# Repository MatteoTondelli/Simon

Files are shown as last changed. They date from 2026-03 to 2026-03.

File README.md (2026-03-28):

# Simon
Arduino version of Milton Bradleys' Simon Game.

# License



Simon  © 2026 by Matteo Tondelli is licensed under Creative Commons Attribution-NonCommercial-ShareAlike 4.0 International. To view a copy of this license, visit https://creativecommons.org/licenses/by-nc-sa/4.0/

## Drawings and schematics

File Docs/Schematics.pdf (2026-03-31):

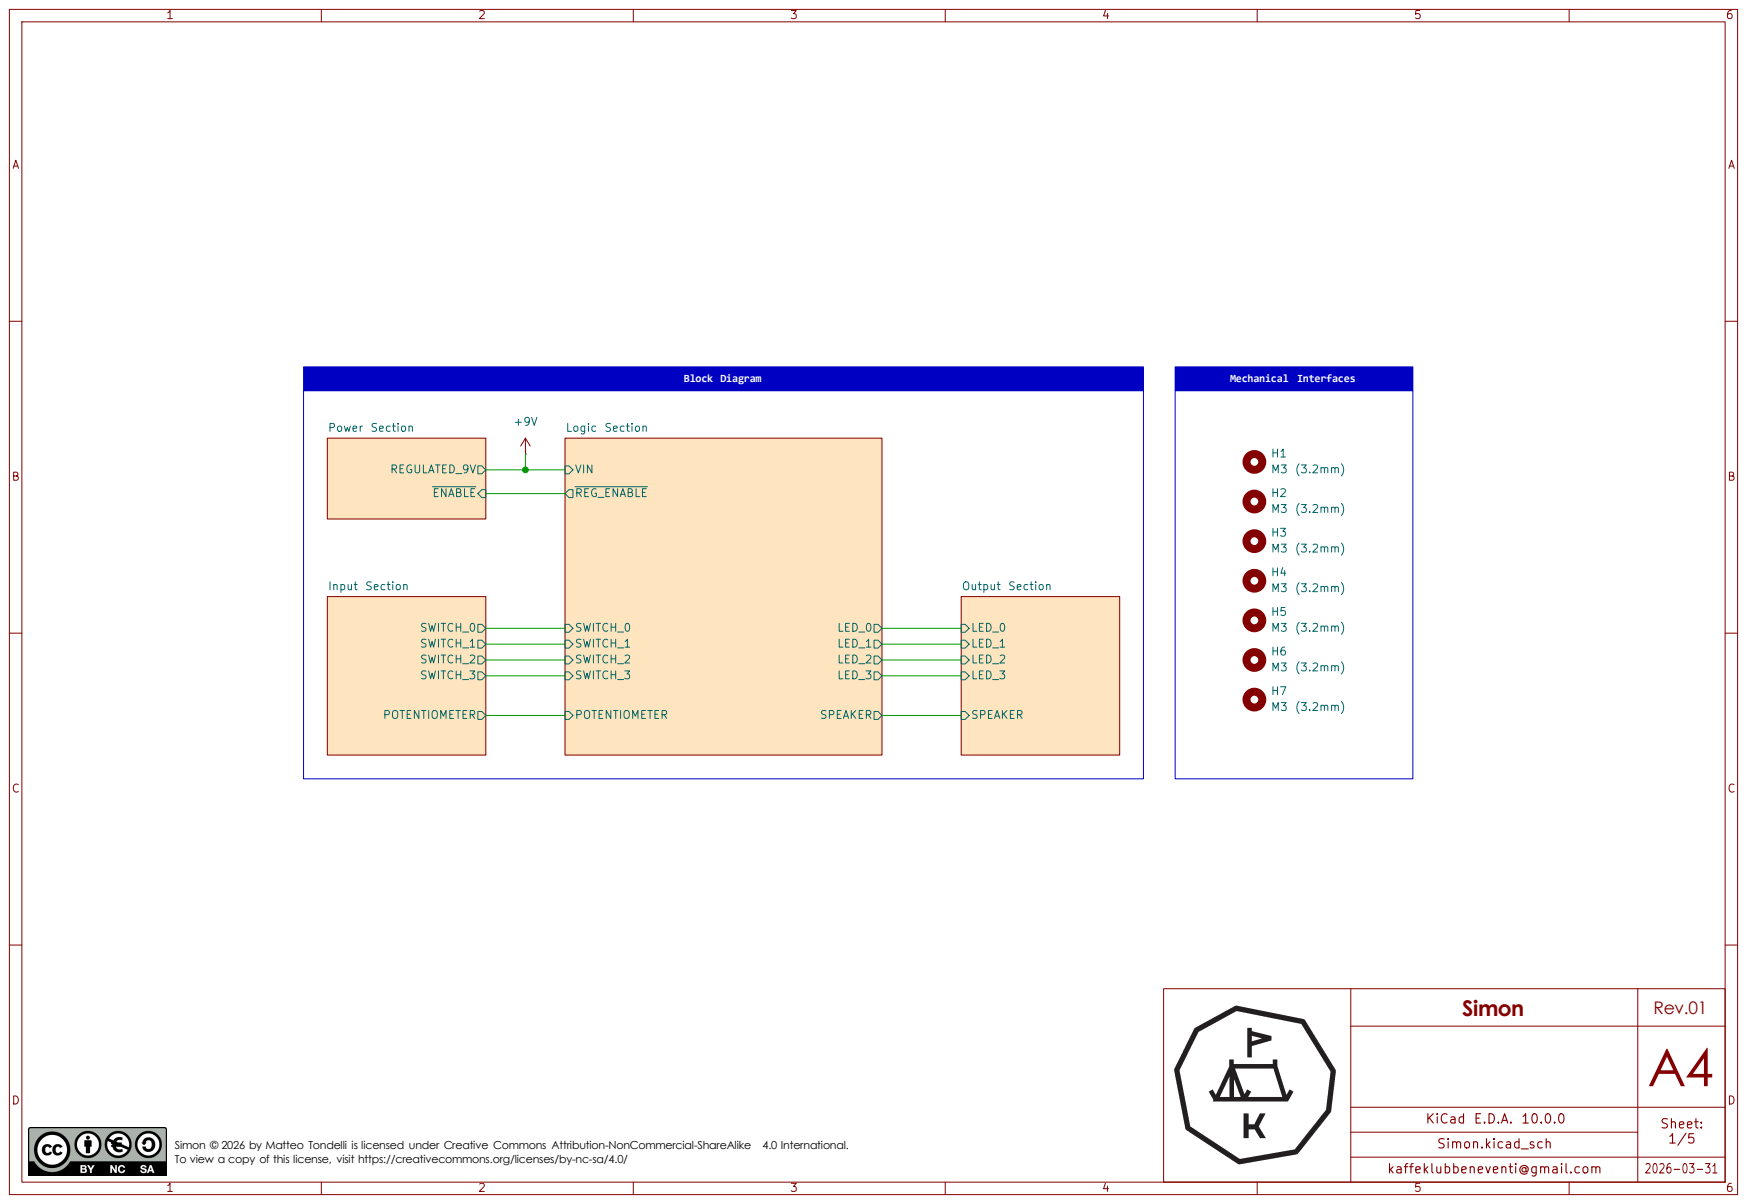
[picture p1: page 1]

Simon
Rev.01 A4 | D 2026-03-31 KiCad E.D.A. 10.0.0

Sheet: 1/5

Simon © 2026 by Matteo Tondelli is licensed under Creative Commons Attribution-NonCommercial-ShareAlike 4.0 International. To view a copy of this license, visit https://creativecommons.org/licenses/by-nc-sa/4.0/

kaffeklubbeneventi@gmail.com

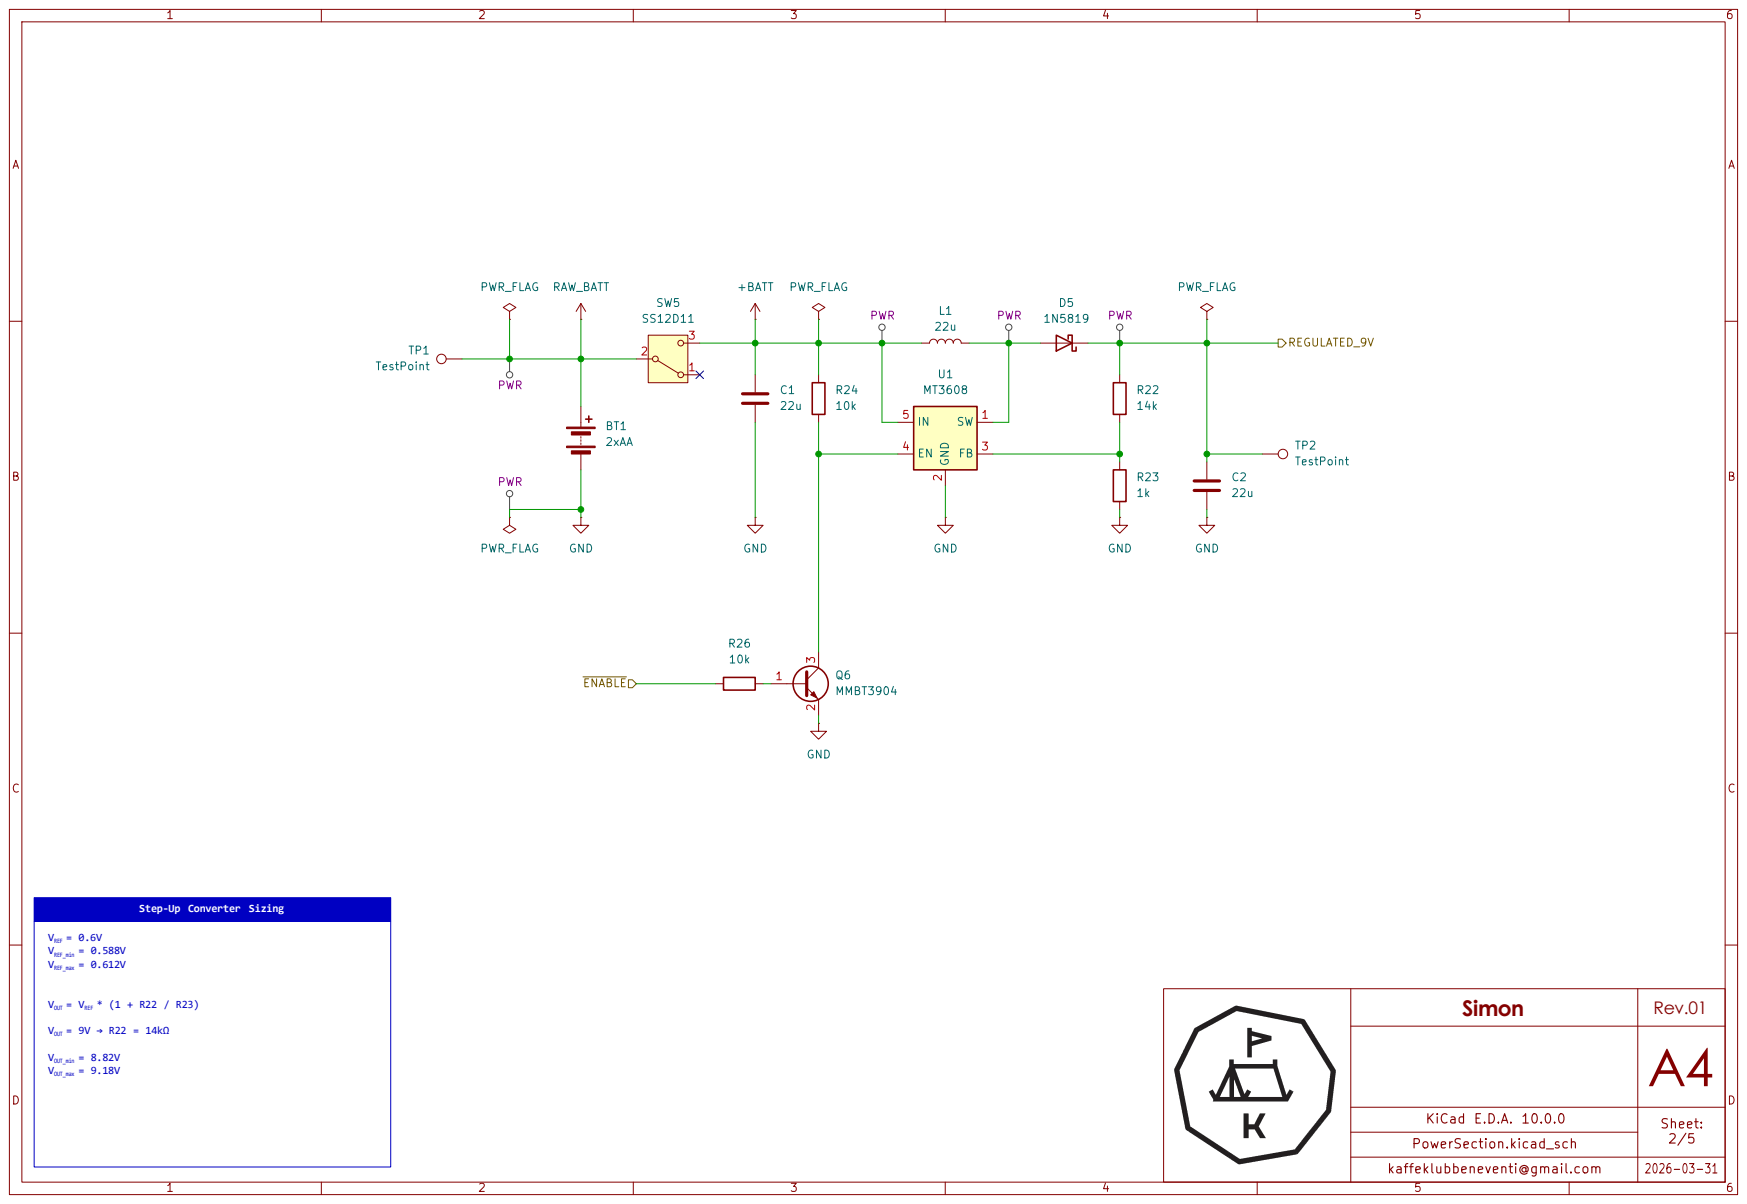
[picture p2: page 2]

Step-Up Converter Sizing

Simon
Rev.01 A4 | D 2026-03-31 KiCad E.D.A. 10.0.0

Sheet: 2/5

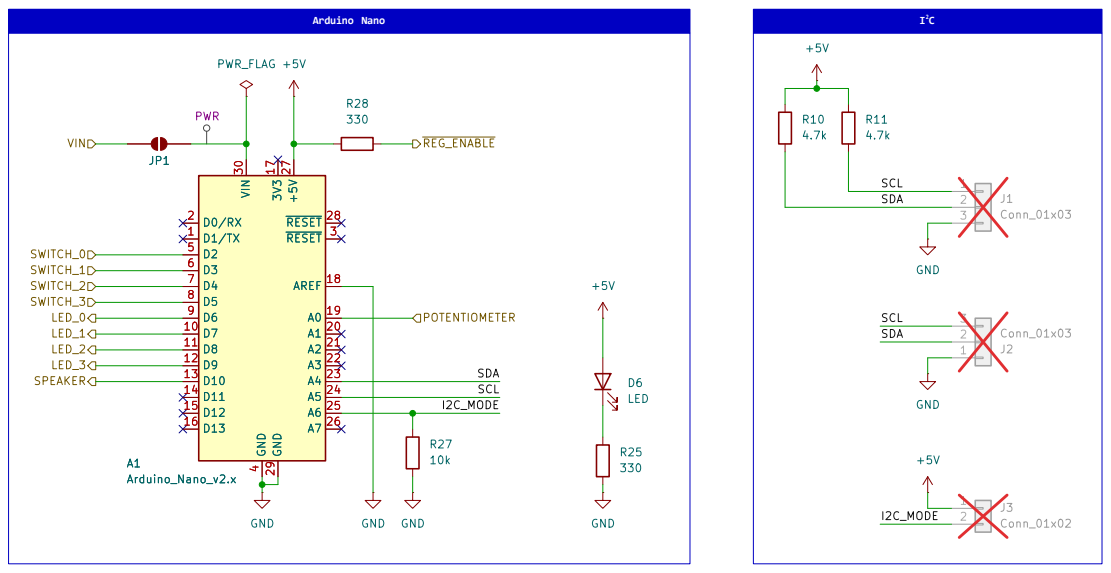
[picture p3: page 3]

Simon
Rev.01 A4 | D 2026-03-31 KiCad E.D.A. 10.0.0

Sheet: 3/5

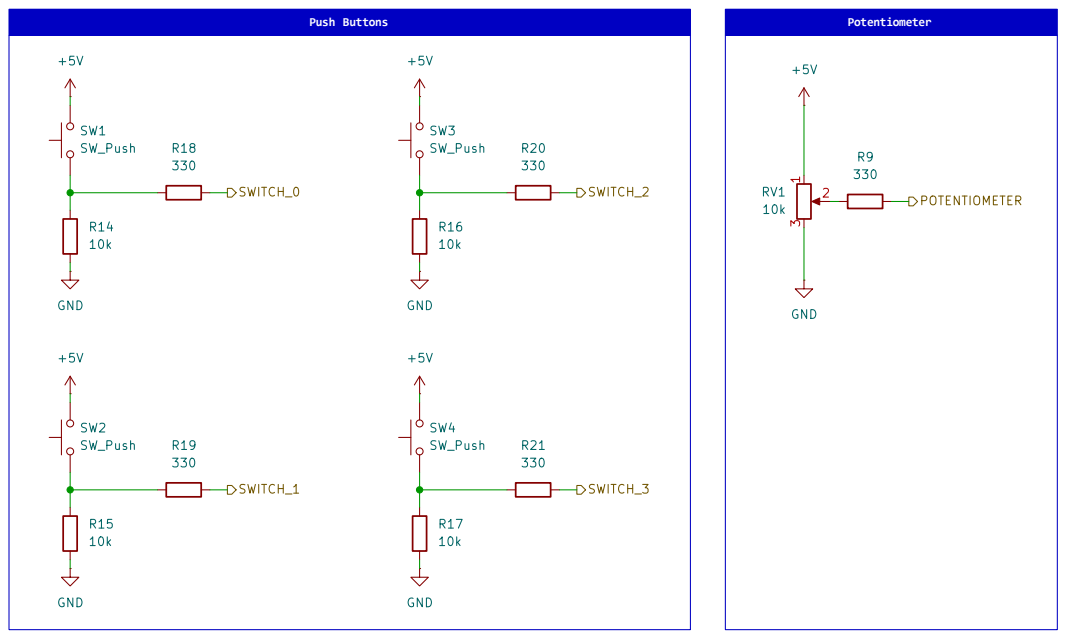
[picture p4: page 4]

Simon
Rev.01 A4 | D 2026-03-31 KiCad E.D.A. 10.0.0

Sheet: 4/5

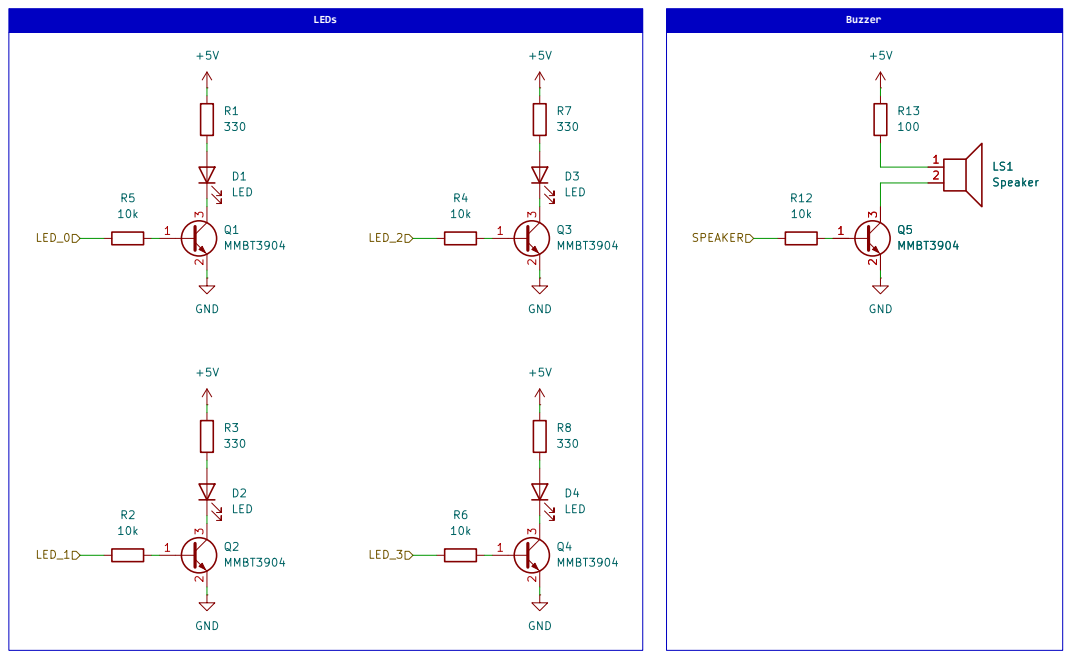
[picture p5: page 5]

Simon
Rev.01 A4 | D 2026-03-31 KiCad E.D.A. 10.0.0

Sheet: 5/5

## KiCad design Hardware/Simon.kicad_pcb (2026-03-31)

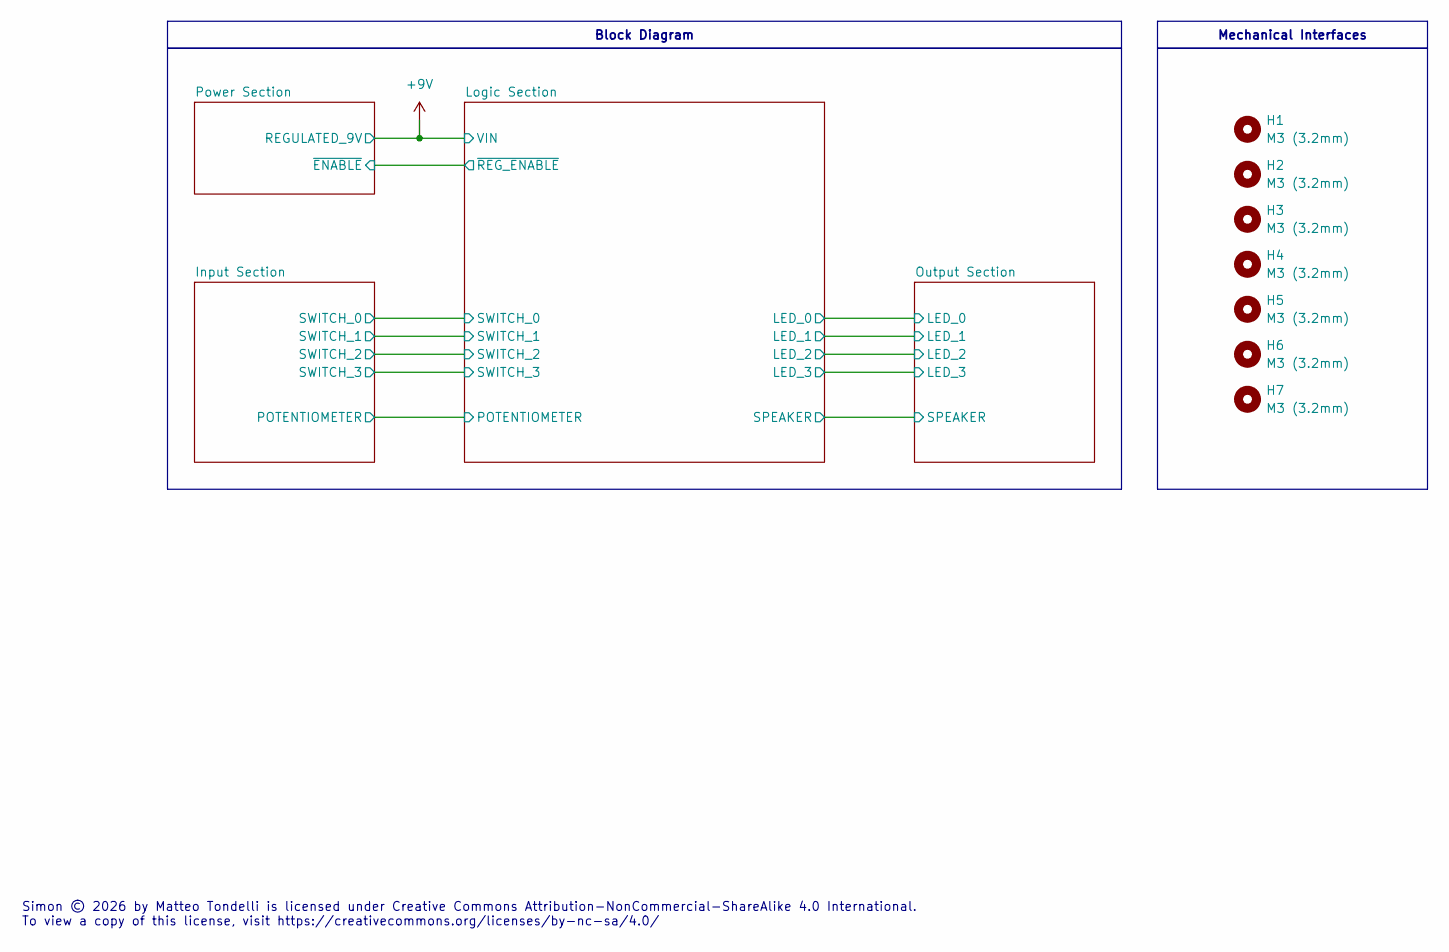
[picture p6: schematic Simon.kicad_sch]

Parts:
H1, H2, H3, H4, H5, H6, H7: M3 (3.2mm); MountingHole_3.2mm_M3

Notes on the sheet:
Simon © 2026 by Matteo Tondelli is licensed under Creative Commons Attribution-NonCommercial-ShareAlike 4.0 International. To view a copy of this license, visit https://creativecommons.org/licenses/by-nc-sa/4.0/
Block Diagram
Mechanical Interfaces

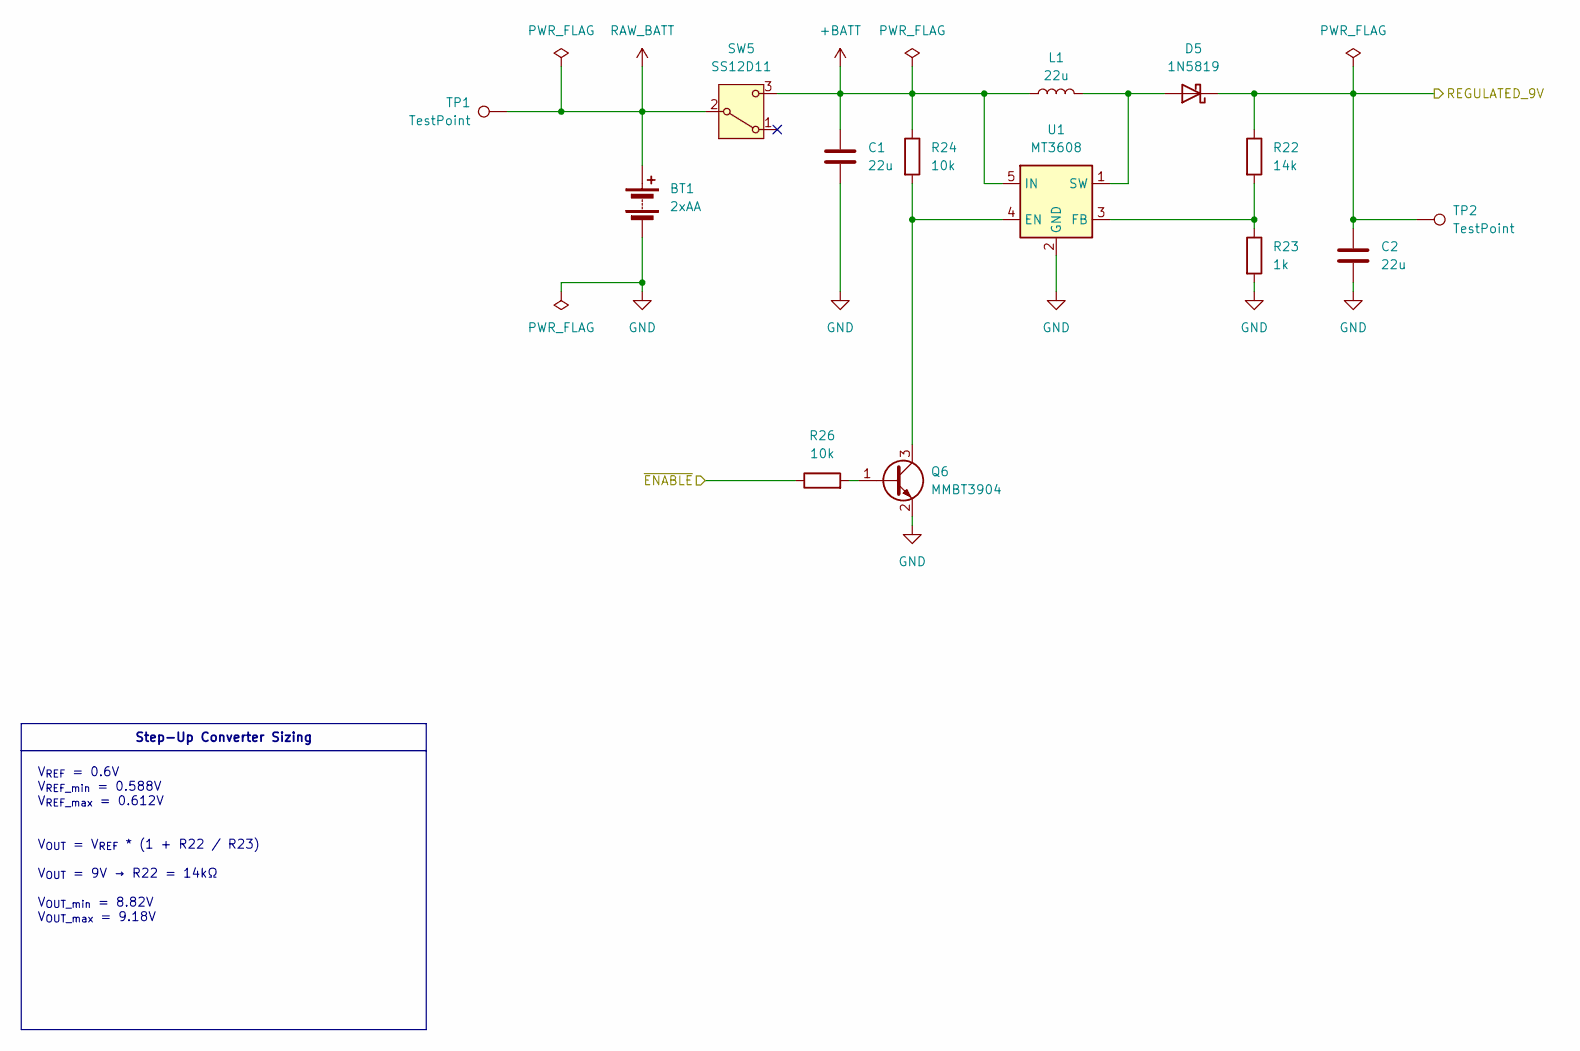
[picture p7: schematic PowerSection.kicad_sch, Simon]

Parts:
BT1: 2xAA; BatteryHolder_Keystone_2462_2xAA
C1, C2: 22u; C_0805_2012Metric
D5: 1N5819; D_SMA
L1: 22u; CDRH104R; MPN CDRH104RNP-220N
Q6: MMBT3904; SOT-23
R22: 14k; R_0805_2012Metric
R23: 1k; R_0805_2012Metric
R24, R26: 10k; R_0805_2012Metric
SW5: SS12D11; SS12D11G5
TP1, TP2: TestPoint; TestPoint_Pad_D1.0mm
U1: MT3608; SOT-23-6

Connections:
+9V: C2.1, D5.1 (K), R22.1, TP2.1 (1_1); also elsewhere on the board
+BATT: C1.1, L1.1, R24.1, SW5.3 (C), U1.5 (IN)
/Logic Section/~REG_ENABLE: R26.1; also elsewhere on the board
GND: BT1.2 (-), C1.2, C2.2, Q6.2 (E), R23.2, U1.2 (GND); also elsewhere on the board
unnamed: D5.2 (A), L1.2, U1.1 (SW)
unnamed: Q6.1 (B), R26.2
unnamed: Q6.3 (C), R24.2, U1.4 (EN)
unnamed: R22.2, R23.1, U1.3 (FB)
RAW_BATT: BT1.1 (+), SW5.2 (B), TP1.1 (1_1)

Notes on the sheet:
Step-Up Converter Sizing
V_{REF} = 0.6V V_{REF_min} = 0.588V V_{REF_max} = 0.612V V_{OUT} = V_{REF} * (1 + R22 / R23) V_{OUT} = 9V → R22 = 14kΩ V_{OUT_min} = 8.82V V_{OUT_max} = 9.18V

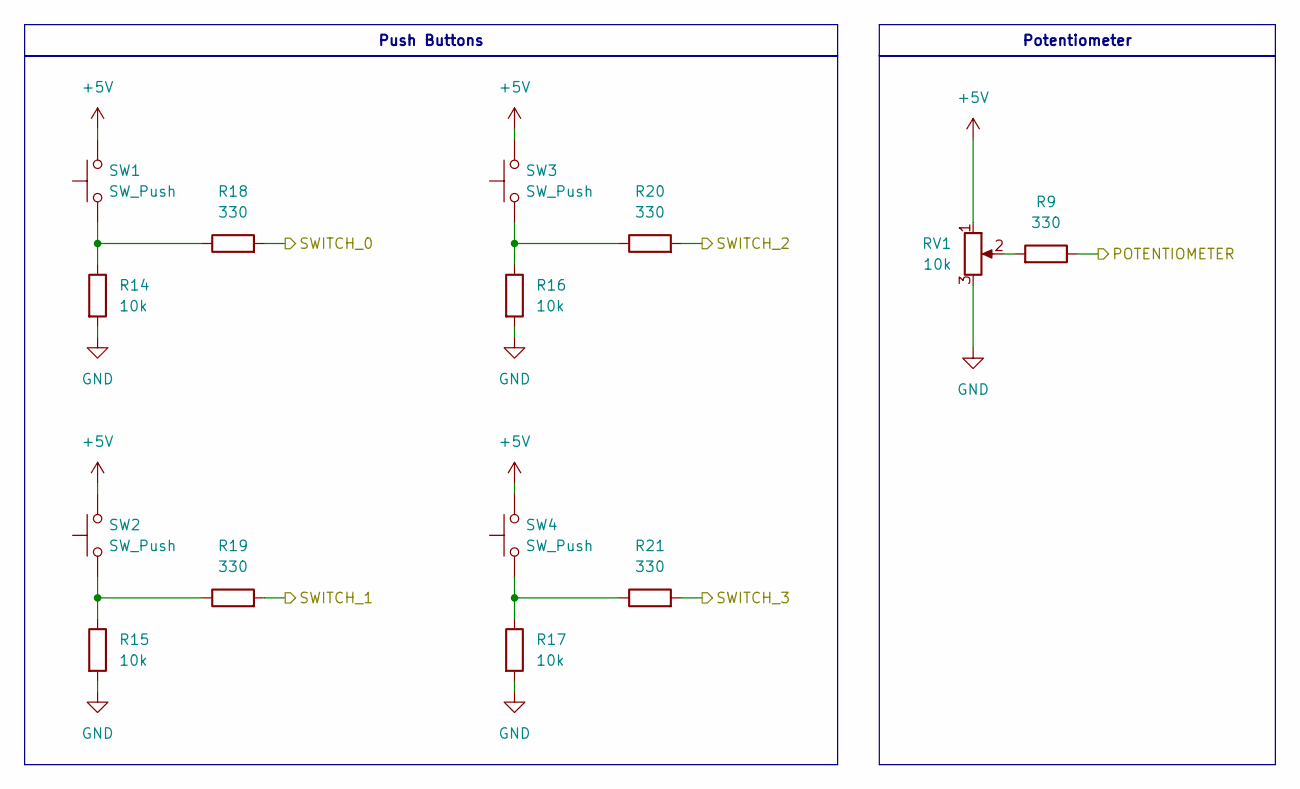
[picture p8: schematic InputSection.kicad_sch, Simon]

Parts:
R9, R18, R19, R20, R21: 330; R_0805_2012Metric
R14, R15, R16, R17: 10k; R_0805_2012Metric
RV1: 10k; Potentiometer_Runtron_RM-065_Vertical; MPN RM065-103
SW1, SW2, SW3, SW4: SW_Push; SW_MX

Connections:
+5V: RV1.1, SW1.2, SW2.2, SW3.2, SW4.2; also elsewhere on the board
/Input Section/POTENTIOMETER: R9.1; also elsewhere on the board
/Input Section/SWITCH_0: R18.2; also elsewhere on the board
/Input Section/SWITCH_1: R19.2; also elsewhere on the board
/Input Section/SWITCH_2: R20.2; also elsewhere on the board
/Input Section/SWITCH_3: R21.2; also elsewhere on the board
GND: R14.2, R15.2, R16.2, R17.2, RV1.3; also elsewhere on the board
unnamed: R9.2, RV1.2
unnamed: R14.1, R18.1, SW1.1
unnamed: R15.1, R19.1, SW2.1
unnamed: R16.1, R20.1, SW3.1
unnamed: R17.1, R21.1, SW4.1

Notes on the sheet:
Push Buttons
Potentiometer

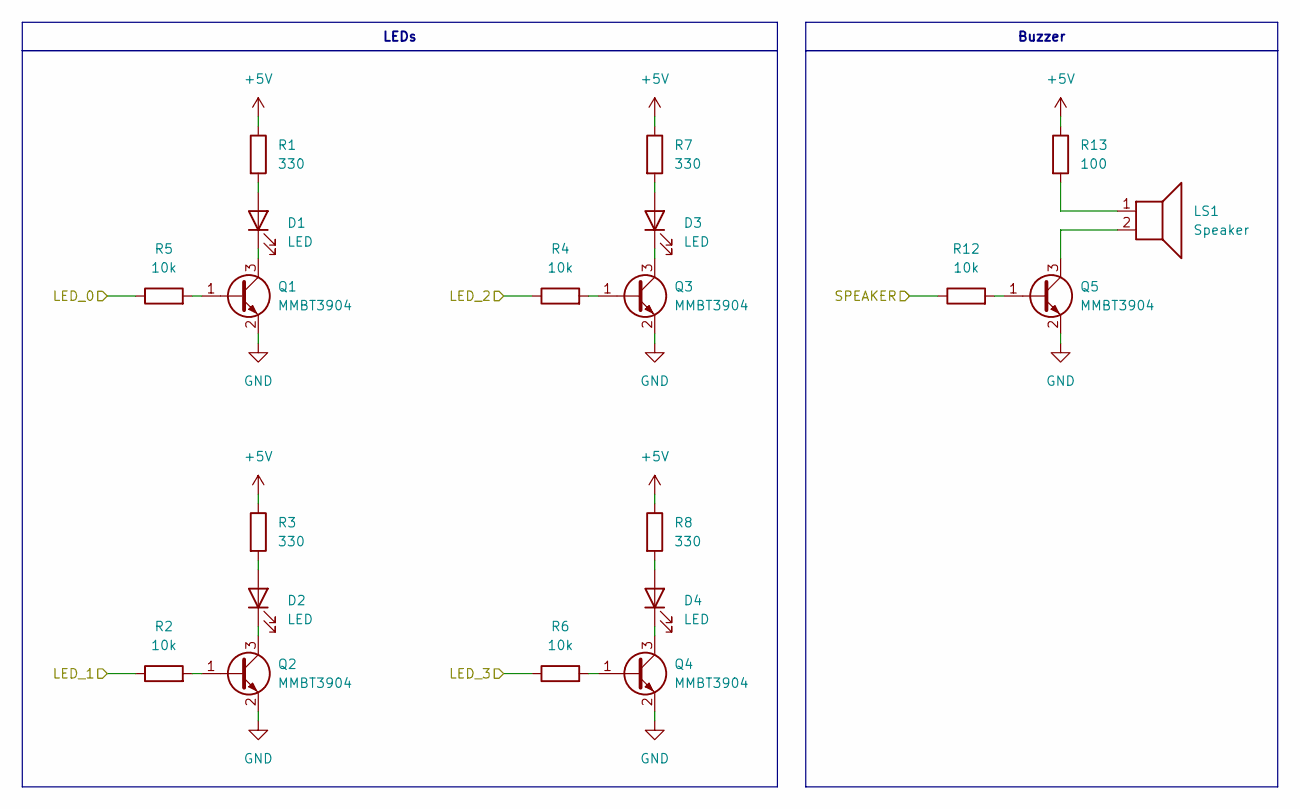
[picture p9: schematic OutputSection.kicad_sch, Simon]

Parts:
D1, D2, D3, D4: LED; LED_D10.0mm
LS1: Speaker; Buzzer
Q1, Q2, Q3, Q4, Q5: MMBT3904; SOT-23
R1, R3, R7, R8: 330; R_0805_2012Metric
R2, R4, R5, R6, R12: 10k; R_0805_2012Metric
R13: 100; R_0805_2012Metric

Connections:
+5V: R1.1, R3.1, R7.1, R8.1, R13.1; also elsewhere on the board
/Logic Section/LED_0: R5.1; also elsewhere on the board
/Logic Section/LED_1: R2.1; also elsewhere on the board
/Logic Section/LED_2: R4.1; also elsewhere on the board
/Logic Section/LED_3: R6.1; also elsewhere on the board
/Logic Section/SPEAKER: R12.1; also elsewhere on the board
GND: Q1.2 (E), Q2.2 (E), Q3.2 (E), Q4.2 (E), Q5.2 (E); also elsewhere on the board
unnamed: D1.2 (A), R1.2
unnamed: D1.1 (K), Q1.3 (C)
unnamed: D2.2 (A), R3.2
unnamed: D2.1 (K), Q2.3 (C)
unnamed: D3.2 (A), R7.2
unnamed: D3.1 (K), Q3.3 (C)
unnamed: D4.2 (A), R8.2
unnamed: D4.1 (K), Q4.3 (C)
unnamed: LS1.1, R13.2
unnamed: Q1.1 (B), R5.2
unnamed: Q2.1 (B), R2.2
unnamed: Q3.1 (B), R4.2
unnamed: Q4.1 (B), R6.2
unnamed: Q5.1 (B), R12.2
unnamed: LS1.2, Q5.3 (C)

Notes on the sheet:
LEDs
Buzzer

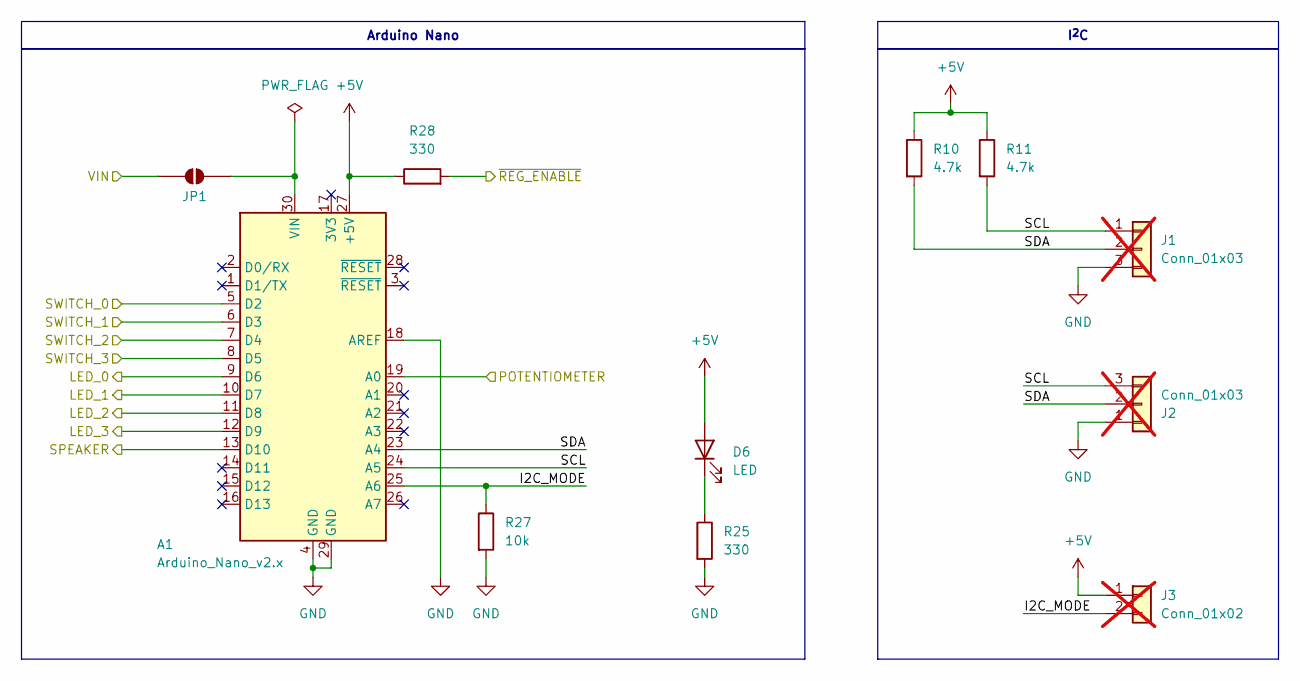
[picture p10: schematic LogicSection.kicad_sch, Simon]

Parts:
A1: Arduino_Nano_v2.x; Arduino_Nano
D6: LED; LED_D3.0mm_Horizontal_O6.35mm_Z2.0mm
J1, J2: Conn_01x03; PinSocket_1x03_P2.54mm_Horizontal; not fitted
J3: Conn_01x02; PinHeader_1x02_P2.54mm_Vertical; not fitted
JP1: SolderJumper_2_Open; SolderJumper-2_P1.3mm_Open_RoundedPad1.0x1.5mm
R10, R11: 4.7k; R_0805_2012Metric
R25, R28: 330; R_0805_2012Metric
R27: 10k; R_0805_2012Metric

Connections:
+5V: A1.27 (+5V), D6.2 (A), J3.1, R10.1, R11.1, R28.1; also elsewhere on the board
+9V: JP1.1 (A); also elsewhere on the board
/Input Section/POTENTIOMETER: A1.19 (A0); also elsewhere on the board
/Input Section/SWITCH_0: A1.5 (D2); also elsewhere on the board
/Input Section/SWITCH_1: A1.6 (D3); also elsewhere on the board
/Input Section/SWITCH_2: A1.7 (D4); also elsewhere on the board
/Input Section/SWITCH_3: A1.8 (D5); also elsewhere on the board
/Logic Section/I2C_MODE: A1.25 (A6), J3.2, R27.1
/Logic Section/LED_0: A1.9 (D6); also elsewhere on the board
/Logic Section/LED_1: A1.10 (D7); also elsewhere on the board
/Logic Section/LED_2: A1.11 (D8); also elsewhere on the board
/Logic Section/LED_3: A1.12 (D9); also elsewhere on the board
/Logic Section/SCL: A1.24 (A5), J1.1, J2.3, R11.2
/Logic Section/SDA: A1.23 (A4), J1.2, J2.2, R10.2
/Logic Section/SPEAKER: A1.13 (D10); also elsewhere on the board
/Logic Section/~REG_ENABLE: R28.2; also elsewhere on the board
GND: A1.4 (GND), A1.18 (AREF), A1.29 (GND), J1.3, J2.1, R25.2, R27.2; also elsewhere on the board
unnamed: A1.30 (VIN), JP1.2 (B)
unnamed: D6.1 (K), R25.1

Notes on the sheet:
I^{2}C
Arduino Nano

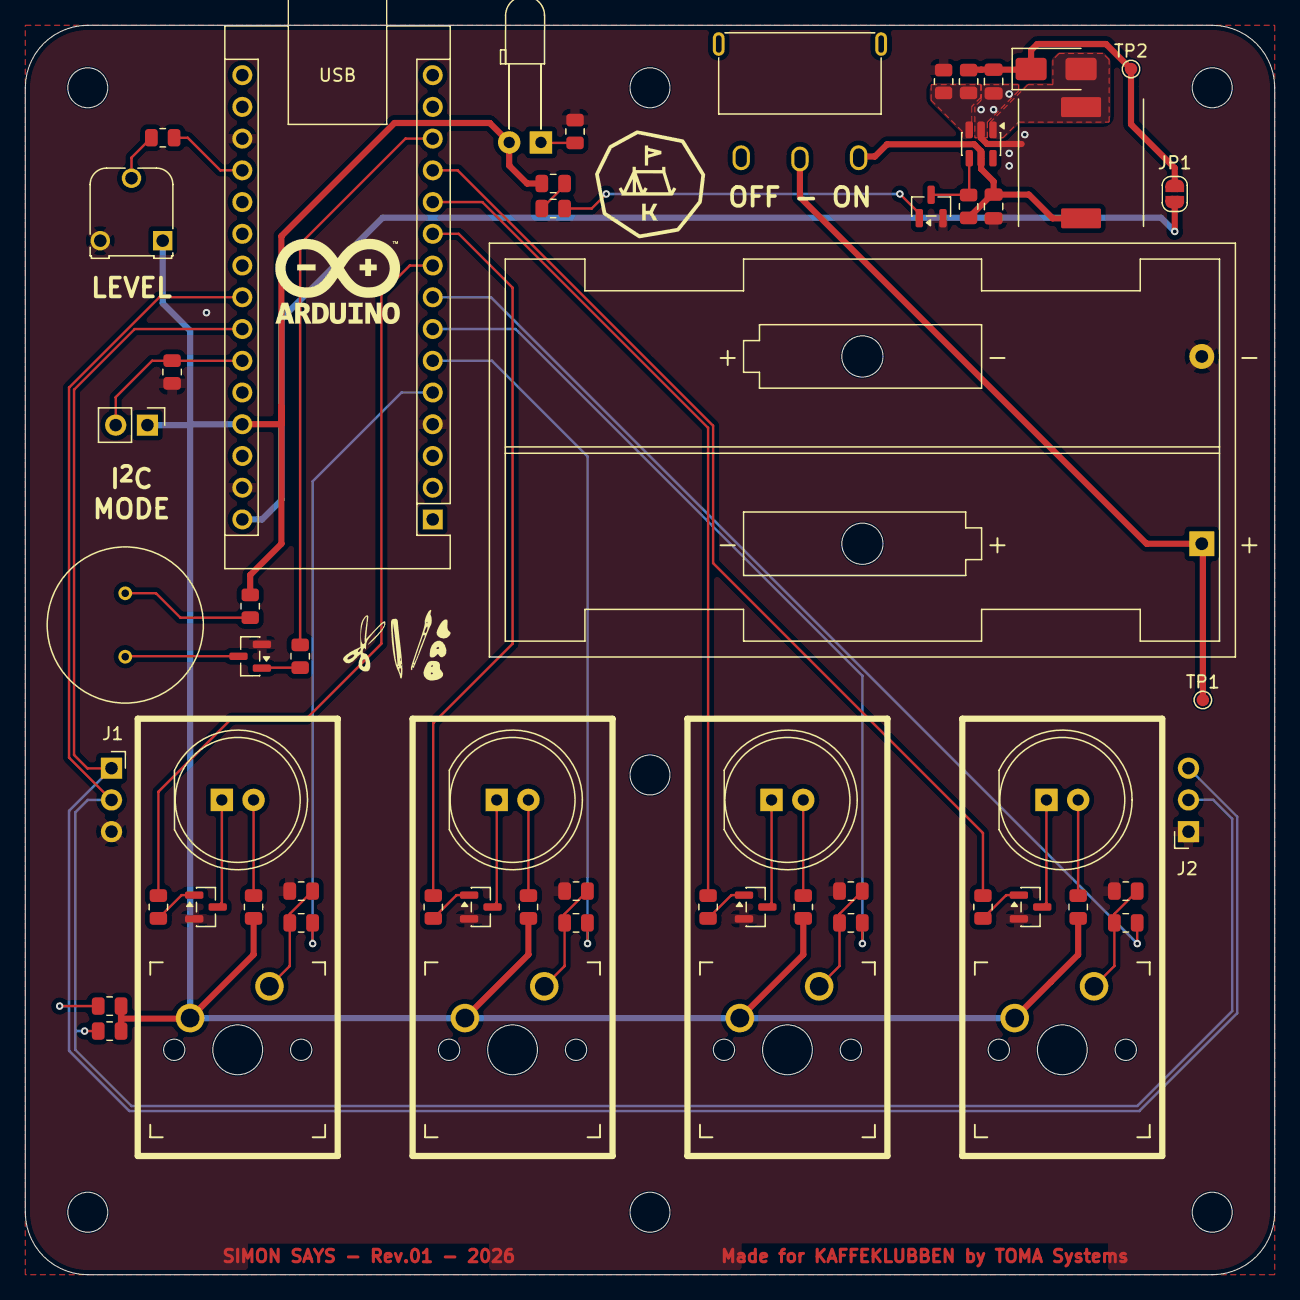
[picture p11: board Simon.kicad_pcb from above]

Board: 2 copper layers, 100.0 x 100.0 mm, 66 parts (0 on the bottom side), 45 nets.

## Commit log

2026-03-28 Added KiCAD project.
    [LogicSection.kicad_sch, OutputSection.kicad_sch, PowerSection.kicad_sch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]
2026-03-28 Updated files to KiCAD 10.
    [InputSection.kicad_sch, LogicSection.kicad_sch, OutputSection.kicad_sch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]
2026-03-31 Added KiCAD local library.
2026-03-31 Updated KiCAD project.
    - Added grouping in schematics.
    - Removed unnecessary net names in "LogicSection.kicad_sch".
    - Added 330R between +5V and nREG_ENABLE.
    - Changed path for 3D models.
    [InputSection.kicad_sch, LogicSection.kicad_sch, OutputSection.kicad_sch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]
2026-03-31 Added schematics PDF.
2026-03-31 Gerber files sent to production.
    [Simon-B_Cu.gbr, Simon-B_Mask.gbr, Simon-B_Paste.gbr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]
